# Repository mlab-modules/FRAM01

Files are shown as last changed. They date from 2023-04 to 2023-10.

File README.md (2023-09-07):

# MLAB module with FRAM memory - CY15B108QN

The MLAB module with FRAM ([Ferroelectric Random Access Memory](https://en.wikipedia.org/wiki/Ferroelectric_RAM)) [CY15B108QN](https://www.infineon.com/dgdl/Infineon-CY15B108QN_CY15V108QN_Excelon(TM)_LP_8-Mbit_(1024K_X_8)_Serial_(SPI)_F-RAM-DataSheet-v11_00-EN.pdf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) provides a unique combination of features that outperform traditional forms of non-volatile memories such as Flash or EEPROM.

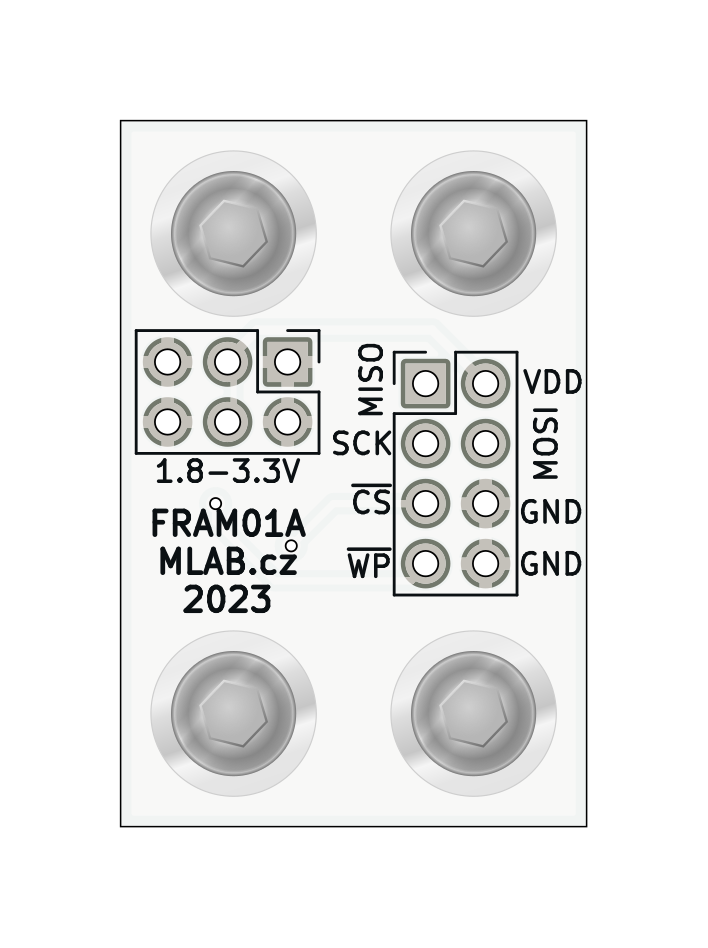
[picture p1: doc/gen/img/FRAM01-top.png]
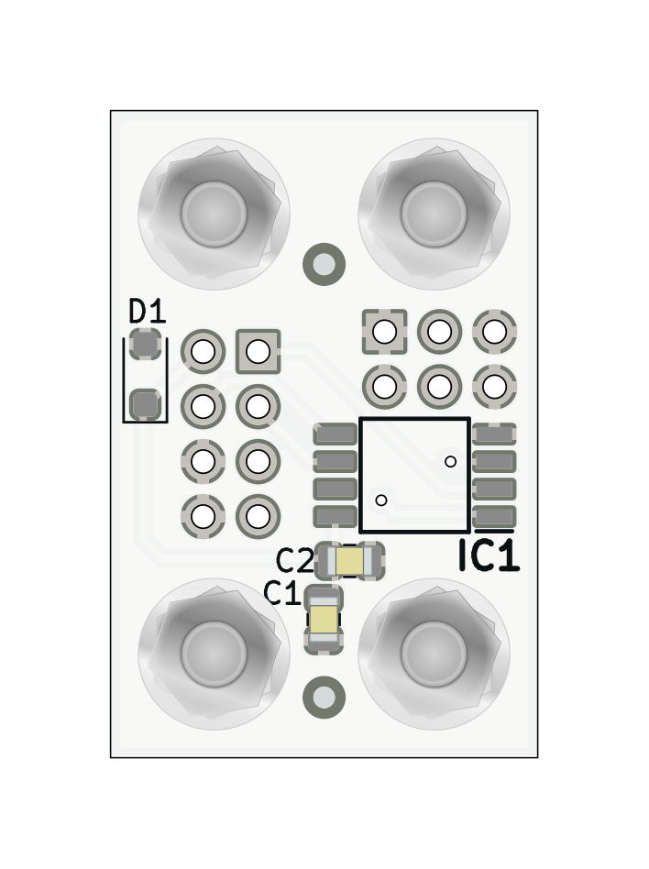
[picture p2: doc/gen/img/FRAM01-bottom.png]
  

## Advantages of FRAM memory

FRAM, also known as Ferroelectric Random Access Memory, offers a range of key advantages that differentiate it and make it suitable for various applications:

1. **Fast data write**: FRAM allows fast data write with speeds comparable to the read speed. This property is much faster than writing data to Flash or EEPROM memories. 

2. **Low power consumption**: The process of writing to FRAM requires less energy than writing to Flash or EEPROM memories due to high speed. 

3. **Very high write/read cycles**: FRAM can undergo approximately 10¹⁵ write and read cycles, which is much more than other forms of non-volatile memories.

4. **High radiation resistance**: Due to its unique physical operation principle, FRAM is more resistant to radiation than other types of memories. The ferroelectric material used to store data can hold an electrical charge without the need for power. This means that once a bit is written to a memory cell, it stays there until something physically changes it. This property, known as polarization, allows FRAM to resist ionizing radiation that can cause random changes in the value of the charge in other types of memories.

For a more comprehensive understanding of FRAM, you can refer to the [FRAM Wikipedia page](https://en.wikipedia.org/wiki/Ferroelectric_RAM).

## Suitable use cases for FRAM memory

Thanks to these unique properties, FRAM is suitable for a range of applications, including:

1. **Industrial automation**: For quick data logging and applications that require a large number of writes.

2. **Energy measurement**: Where there is a need to write data quickly and frequently with low energy consumption.

3. **Automotive applications**: FRAM is resistant to radiation and temperature fluctuations, making it ideal for use in the automotive industry.

4. **Aerospace and defense applications**: Thanks to its resistance to ionizing radiation, FRAM is an ideal choice for applications that are exposed to high levels of radiation.

## Parameters of CY15B108QN FRAM memory

- Capacity: 8 Mbit (1024K x 8)
- Power supply: 1.8V to 3.6V
- Interface: SPI, up to 40 MHz
- Write speed: 14 ns
- Endurance: 10^15 write and read cycles
- Data retention: 151 years at 85°C

For detailed information on CY15B108QN FRAM memory, please refer to the [datasheet](https://www.infineon.com/dgdl/Infineon-CY15B108QN_CY15V108QN_Excelon(TM)_LP_8-Mbit_(1024K_X_8)_Serial_(SPI)_F-RAM-DataSheet-v11_00-EN.pdf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).

This module is perfectly tailored for demanding applications that require high write speed, high reliability and durability, and low power consumption. Take advantage of the benefits of FRAM memory in the MLAB module with CY15B108QN.

## Module schematics
Link to FRAM01 schematic

## Overview of the MLAB module form factor

The [MLAB](https://mlab.cz/) modules provide a standard for developing modular solutions. They offer versatile usage as they can be either standalone modules for specific tasks or used as building blocks for more complex systems. The compact form factor along with the robust design of the MLAB modules ensures their effectiveness in a variety of applications. The MLAB system contains a wide range of electronic modules, each serving a specific function, which allows for great flexibility in designing electronic systems.

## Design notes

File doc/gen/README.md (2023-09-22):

# PCB

Board size: 19.81x29.97 mm (0.78x1.18 inches)

- This is the size of the rectangle that contains the board
- Thickness: 1.6 mm (63 mils)
- Material: FR4
- Finish: None
- Layers: 2
- Copper thickness: 35 µm

Solder mask: TOP / BOTTOM

- Color: Green

Silk screen: TOP / BOTTOM

- Color: White

Stackup:

| Name | Type | Color | Thickness | Material | Epsilon_r | Loss tangent |
|---|---|---|---|---|---|---|
| F.SilkS | Top Silk Screen | | | | | |
| F.Paste | Top Solder Paste | | | | | |
| F.Mask | Top Solder Mask | | 10 | | | |
| F.Cu | copper | | 35 | | | |
| dielectric 1 | core | | 1510 | FR4 | 4.5 | 0.020 |
| B.Cu | copper | | 35 | | | |
| B.Mask | Bottom Solder Mask | | 10 | | | |
| B.Paste | Bottom Solder Paste  | | | | | |
| B.SilkS | Bottom Silk Screen | | | | | |

# Important sizes

Clearance: 0.2 mm (8 mils)

Track width: 0.25 mm (10 mils)

- By design rules: 0.2 mm (8 mils)

Drill: 0.5 mm (20 mils)

- Vias: 0.5 mm (20 mils) [Design: 0.4 mm (16 mils)]
- Pads: 1.1 mm (43 mils)
- The above values are real drill sizes, they add 0.1 mm (4 mils) to plated holes (PTH)

Via: 0.8/0.4 mm (31/16 mils)

- By design rules: 0.4/0.3 mm (16/12 mils)
- Micro via: yes [0.2/0.1 mm (8/4 mils)]
- Buried/blind via: yes
- Total: 2 (thru: 2 buried/blind: 0 micro: 0)

Outer Annular Ring: 0.15 mm (6 mils)

- By design rules: 0.3 mm (12 mils)

Eurocircuits class: 4B
- Using min drill 0.5 mm for an OAR of 0.15 mm

# General stats

Components count: (SMD/THT)

- Top: 0/6 (THT)
- Bottom: 6/0 (SMD)

Defined tracks:

Used tracks:

- 0.25 mm (10 mils) (1) defined: no
- 0.3 mm (12 mils) (7) defined: no
- 0.3 mm (12 mils) (18) defined: no
- 0.4 mm (16 mils) (3) defined: no

Defined vias:

Used vias:

- 0.8/0.4 mm (31/16 mils) (Count: 2, Aspect: 2.0 A) defined: no

Holes (excluding vias):

- 1.0 mm (39 mils) (14)
- 3.0 mm (118 mils) (4)

Oval holes:

Drill tools (including vias and computing adjusts and rounding):

- 0.5 mm (20 mils) (2)
- 1.1 mm (43 mils) (14)
- 3.1 mm (122 mils) (4)

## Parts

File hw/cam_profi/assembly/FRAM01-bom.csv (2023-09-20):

Component | Description | Part | References | Value | Footprint | Quantity Per PCB | Datasheet | ust_id | height | manufacturer_name | manufacturer_part_number | mouser part number | mouser price/stock
1 |  | C_Small-Device-ISM02A-rescue | C2 | 100nF | C_0805_2012Metric | 1 |  | 5c70984712875079b91f8b4c
2 |  | C_Small-Device-ISM02A-rescue | C1 | 10uF | C_0805_2012Metric | 1 |  | 5c70984812875079b91f8bbe
3 |  | D_ZENER-MLAB_D | D1 | BZT52H-C3V6,115 | D_SOD-123F | 1 | BZT52H-C3V6,115 | 650b35ab462c6d9e720543d0
4 | F-RAM Excelon LP 40 MHz 8-EIAJ | CY15B108QN-40SXI | IC1 | CY15B108QN-40SXI | SOIC127P800X203-8N | 1 | https://www.mouser.in/datasheet/2/196/CYPR_S_A0011123055_1-3004611.pdf | 650b3dae462c6d9e72054477 | 2.03 | Infineon / Cypress | CY15B108QN-40SXI | 727-CY15B108QN-40SXI | https://www.mouser.co.uk/ProductDetail/Infineon-Cypress/CY15B108QN-40SXI?qs=P1JMDcb91o4DSS%2FkAQM5uA%3D%3D
5 | 2x03 2.54 mm pitch header, 2 pins next to each other are connected | HEADER_2x03_PARALLEL | J1 | HEADER_2x03_PARALLEL | PinHeader_2x03_P2.54mm_Vertical | 1
6 | 2x04 2.54 mm pitch header | HEADER_2x04 | J2 | HEADER_2x04 | PinHeader_2x04_P2.54mm_Vertical | 1

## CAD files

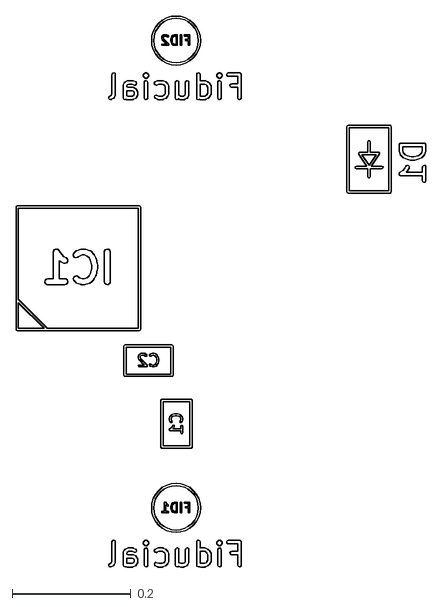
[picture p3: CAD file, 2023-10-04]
doc/gen/dxf/FRAM01-B_Fab.dxf
0.691 x 0.928

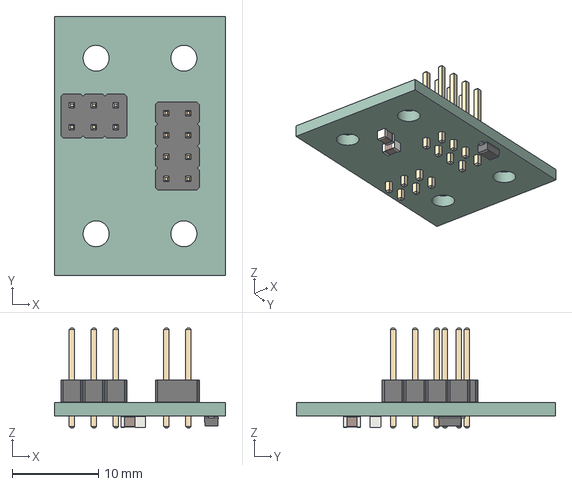
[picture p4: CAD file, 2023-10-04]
doc/gen/FRAM01.step
19.8 x 30.0 x 11.5 mm
tmpsu2gkpzn PCB

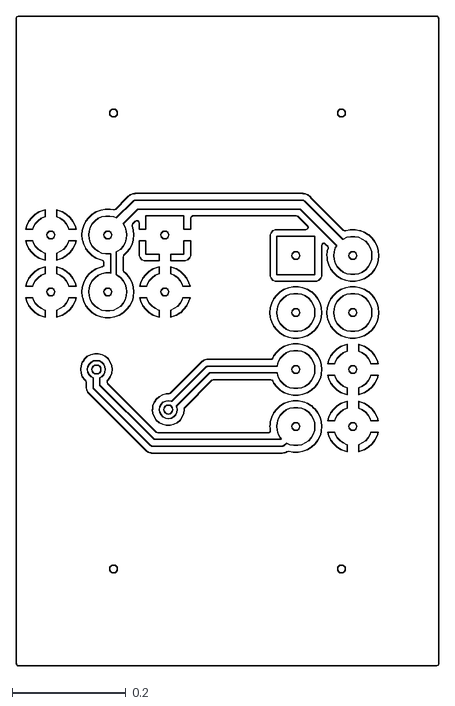
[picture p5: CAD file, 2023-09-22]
doc/gen/dxf/FRAM01-F_Cu.dxf
0.741 x 1.14

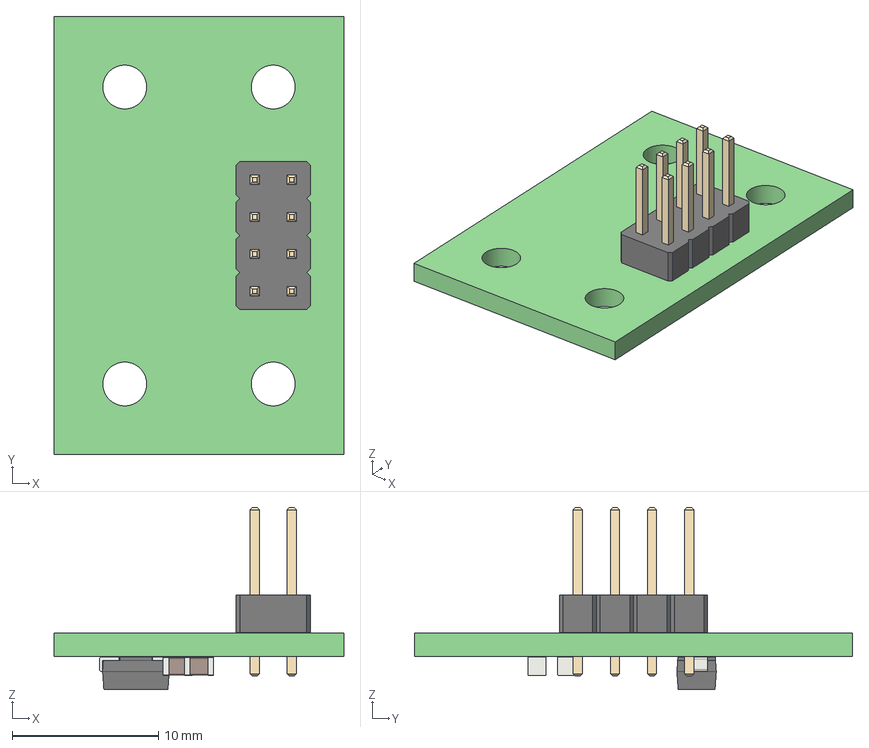
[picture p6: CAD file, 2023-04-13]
doc/gen/FRAM01A.step
19.8 x 30.0 x 12.5 mm
tmpce5b5qsc PCB

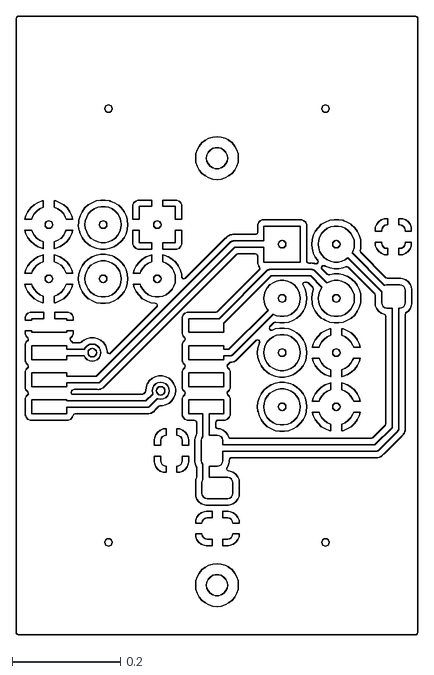
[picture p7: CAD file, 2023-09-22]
doc/gen/dxf/FRAM01-B_Cu.dxf
0.741 x 1.14

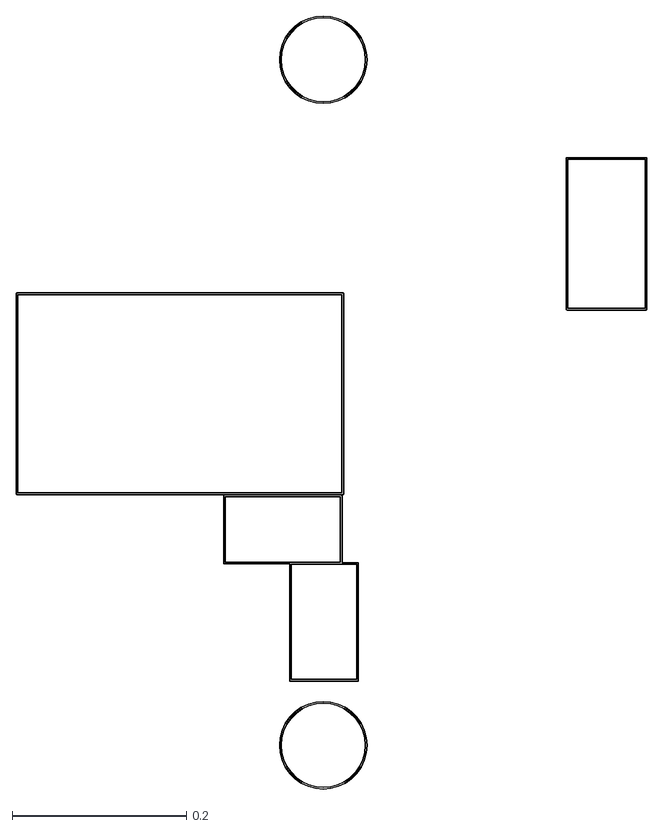
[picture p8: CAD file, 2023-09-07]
doc/gen/dxf/FRAM01-B_Courtyard.dxf
0.724 x 0.888

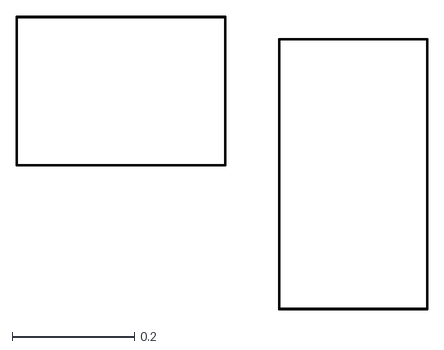
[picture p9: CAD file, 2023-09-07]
doc/gen/dxf/FRAM01-F_Courtyard.dxf
0.673 x 0.479

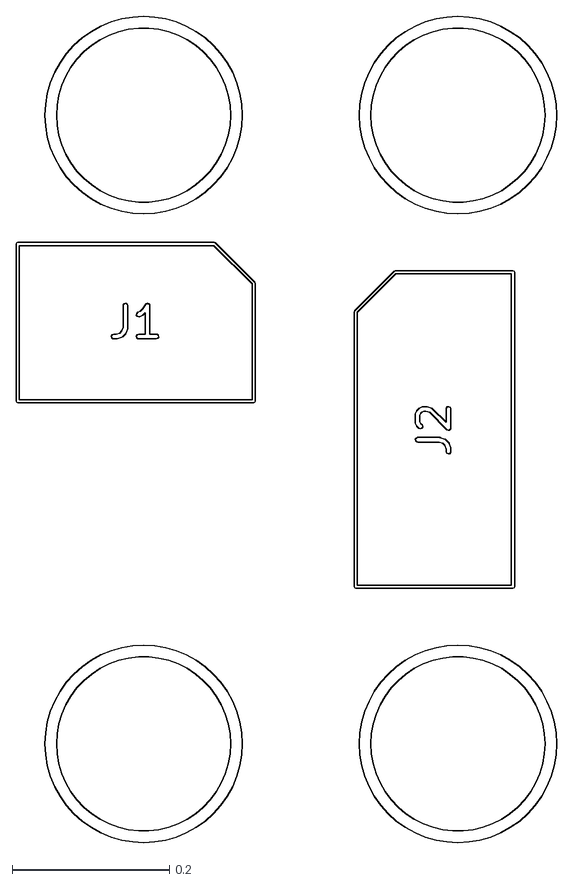
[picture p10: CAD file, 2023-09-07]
doc/gen/dxf/FRAM01-F_Fab.dxf
0.688 x 1.05

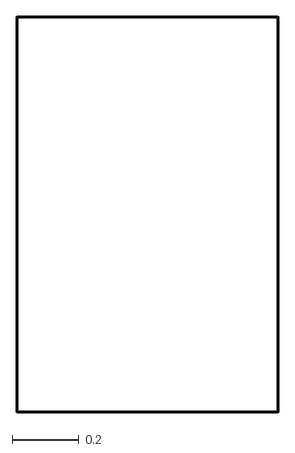
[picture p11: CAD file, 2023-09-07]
doc/gen/dxf/FRAM01-Edge_Cuts.dxf
0.785 x 1.19

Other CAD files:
doc/gen/dxf/FRAM01A-User_4.dxf
doc/gen/dxf/FRAM01A-User_2.dxf
doc/gen/dxf/FRAM01-Margin.dxf
doc/gen/dxf/FRAM01A-B_Adhesive.dxf
doc/gen/dxf/FRAM01A-User_Eco1.dxf
doc/gen/dxf/FRAM01A-User_Eco2.dxf
doc/gen/dxf/FRAM01-User_5.dxf
doc/gen/dxf/FRAM01-User_4.dxf
doc/gen/dxf/FRAM01A-User_3.dxf
doc/gen/dxf/FRAM01-B_Adhesive.dxf
doc/gen/dxf/FRAM01-B_Mask.dxf
doc/gen/dxf/FRAM01-B_Paste.dxf
doc/gen/dxf/FRAM01-B_Silkscreen.dxf
doc/gen/dxf/FRAM01-F_Adhesive.dxf
doc/gen/dxf/FRAM01-F_Mask.dxf
doc/gen/dxf/FRAM01-F_Paste.dxf
doc/gen/dxf/FRAM01-F_Silkscreen.dxf
doc/gen/dxf/FRAM01-User_1.dxf
doc/gen/dxf/FRAM01-User_2.dxf
doc/gen/dxf/FRAM01-User_3.dxf
doc/gen/dxf/FRAM01-User_6.dxf
doc/gen/dxf/FRAM01-User_7.dxf
doc/gen/dxf/FRAM01-User_8.dxf
doc/gen/dxf/FRAM01-User_9.dxf
doc/gen/dxf/FRAM01-User_Comments.dxf
doc/gen/dxf/FRAM01-User_Drawings.dxf
doc/gen/dxf/FRAM01-User_Eco1.dxf
doc/gen/dxf/FRAM01-User_Eco2.dxf
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

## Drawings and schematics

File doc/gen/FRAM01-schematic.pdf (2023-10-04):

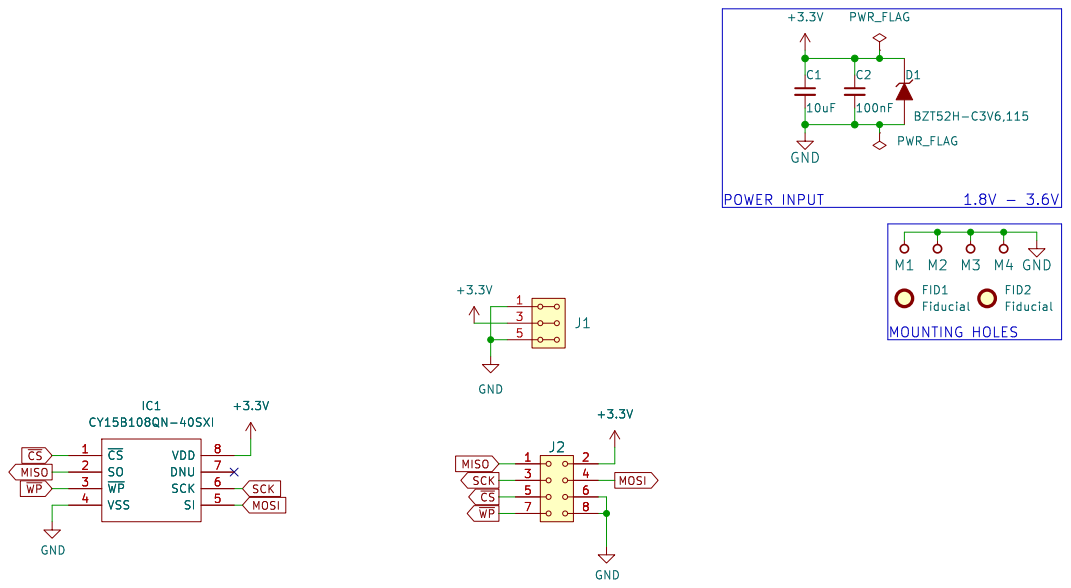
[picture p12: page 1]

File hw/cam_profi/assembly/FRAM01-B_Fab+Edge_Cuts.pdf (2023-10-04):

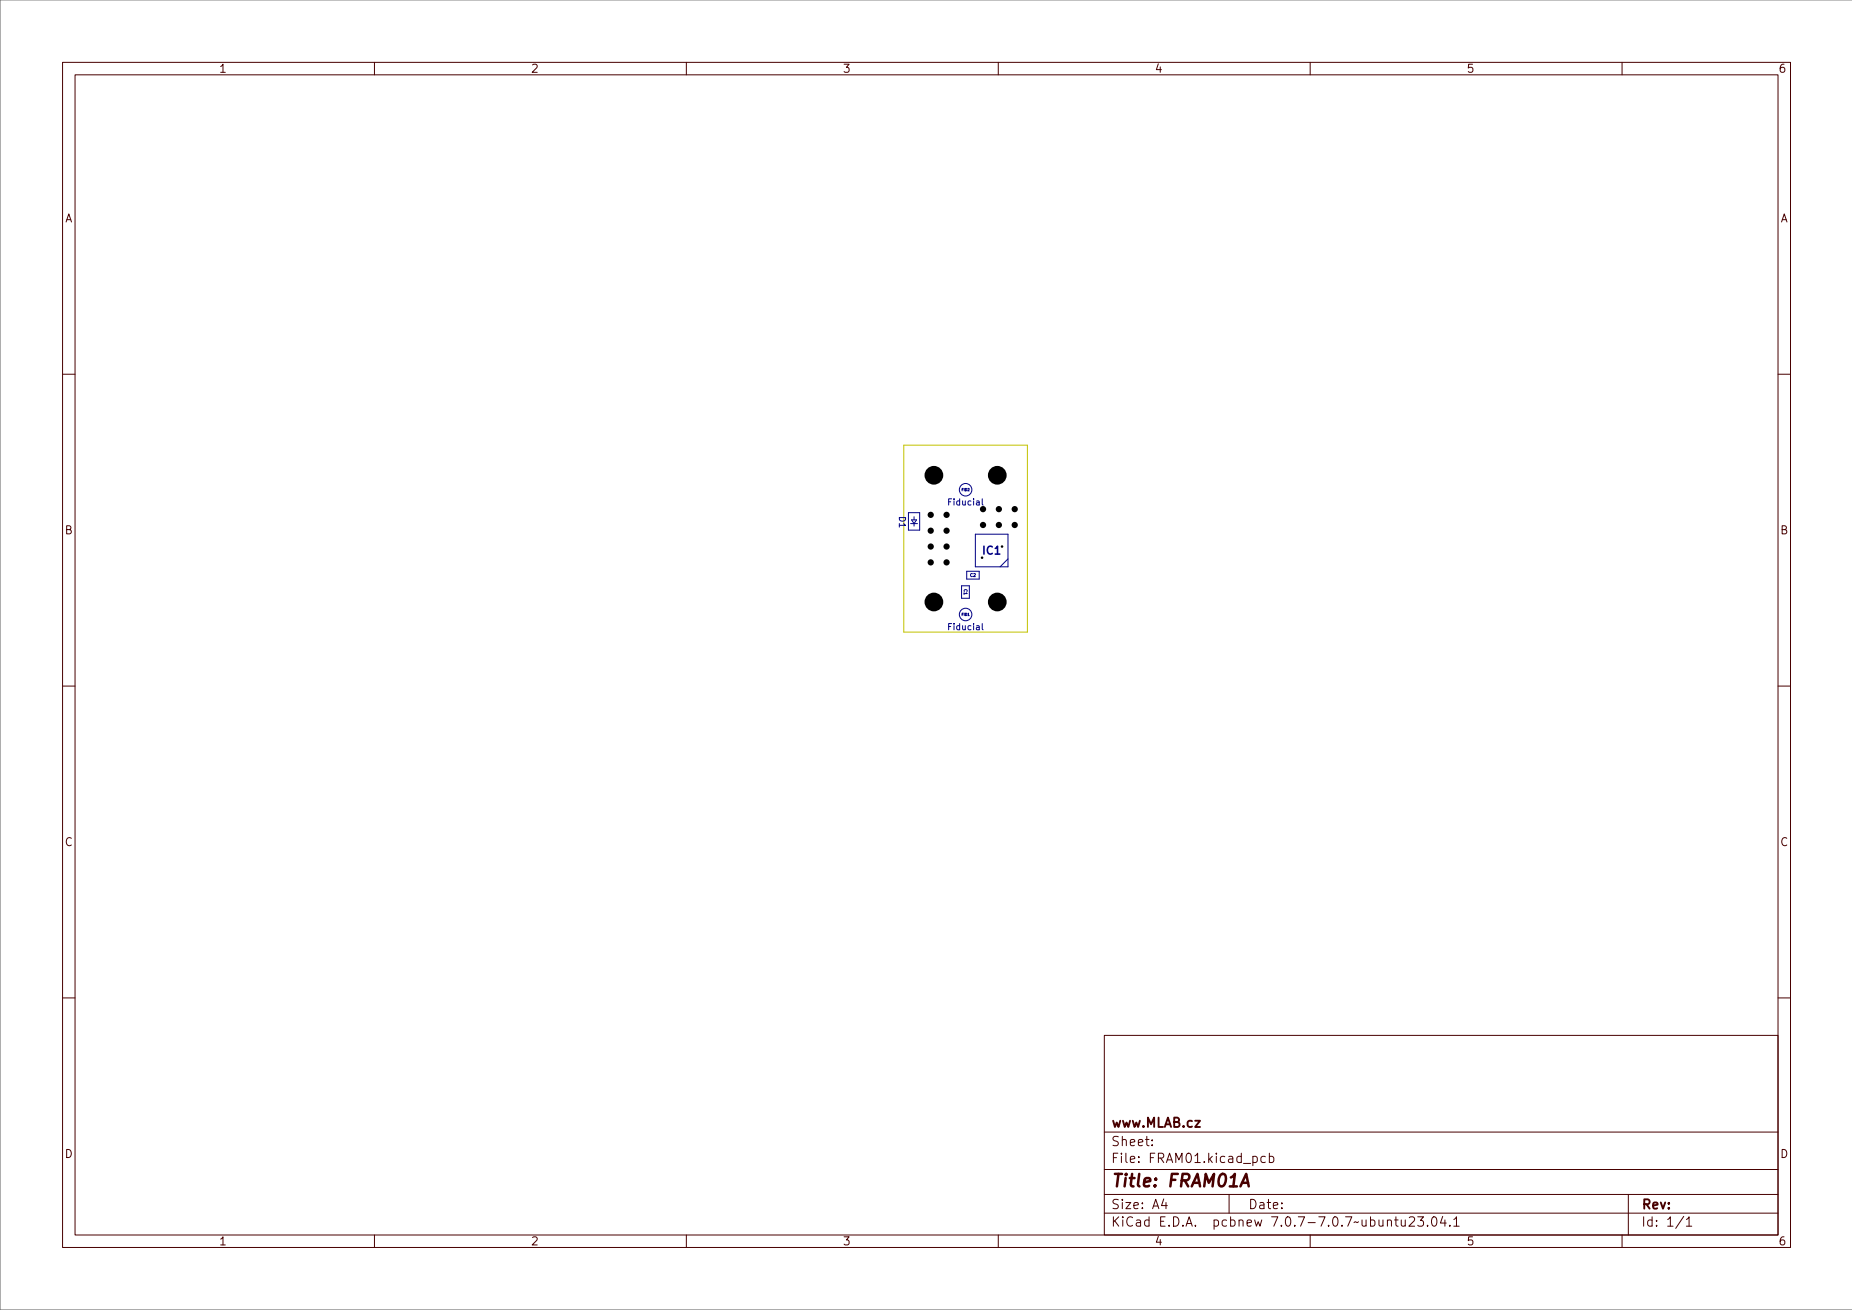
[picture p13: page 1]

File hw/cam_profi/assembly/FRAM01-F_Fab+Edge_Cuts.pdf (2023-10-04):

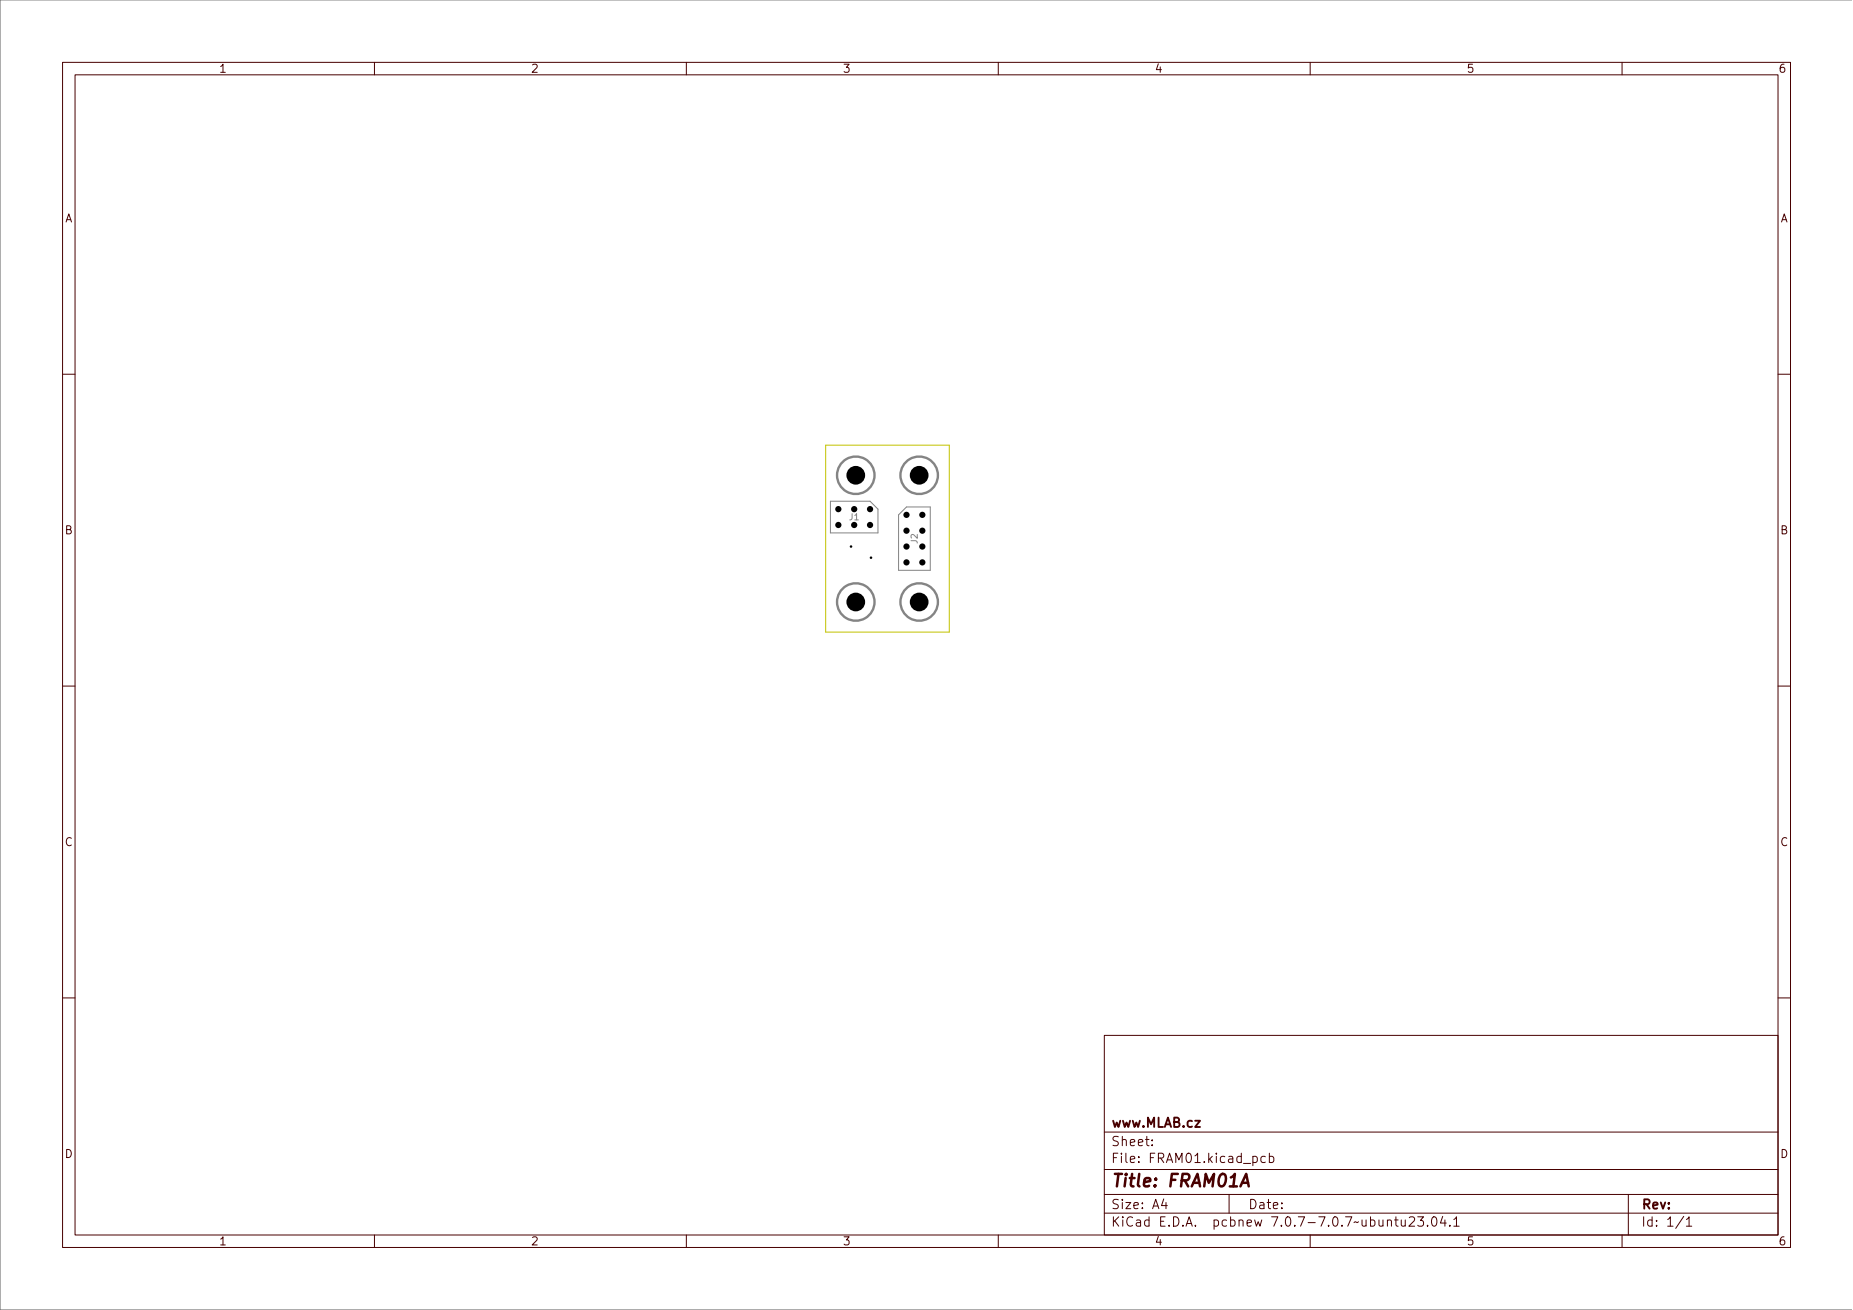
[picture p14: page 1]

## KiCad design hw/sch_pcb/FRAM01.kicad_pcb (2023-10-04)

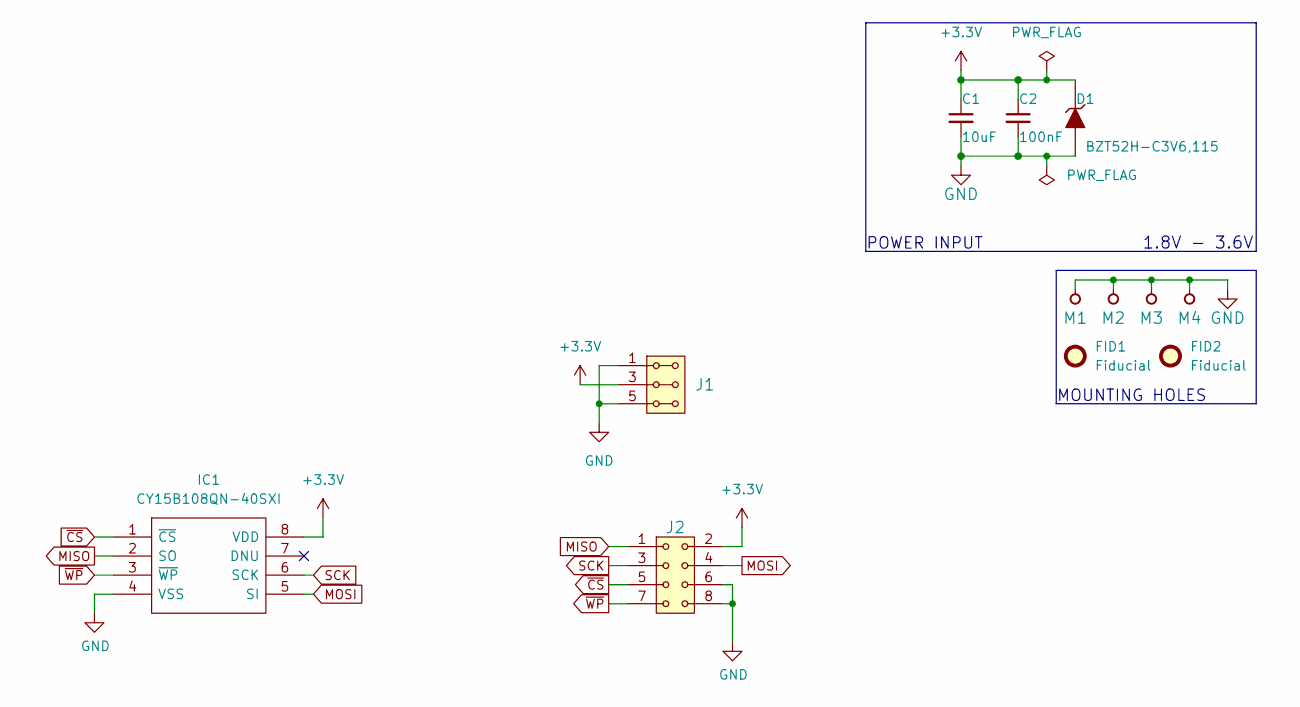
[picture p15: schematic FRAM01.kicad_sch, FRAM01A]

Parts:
C1: 10uF; C_0805_2012Metric
C2: 100nF; C_0805_2012Metric
D1: BZT52H-C3V6,115; D_SOD-123F
FID1, FID2: Fiducial; Fiducial_1mm_Mask2mm
IC1: CY15B108QN-40SXI; SOIC127P800X203-8N; Mouser Part Number 727-CY15B108QN-40SXI
J1: HEADER_2x03_PARALLEL; PinHeader_2x03_P2.54mm_Vertical
J2: HEADER_2x04; PinHeader_2x04_P2.54mm_Vertical
M1, M2: HOLE M3; MountingHole_3mm
M3, M4: HOLE; MountingHole_3mm

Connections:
+3.3V: C1.1, C2.1, D1.1 (K), IC1.8 (VDD), J1.3, J1.4, J2.2
GND: C1.2, C2.2, D1.2 (A), IC1.4 (VSS), J1.1, J1.2, J1.5, J1.6, J2.6, J2.8, M1.1, M2.1, M3.1, M4.1
MISO: IC1.2 (SO), J2.1
MOSI: IC1.5 (SI), J2.4
SCK: IC1.6 (SCK), J2.3
~CS: IC1.1 (~CS), J2.5
~WP: IC1.3 (~WP), J2.7

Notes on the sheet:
1.8V - 3.6V
POWER INPUT
MOUNTING HOLES

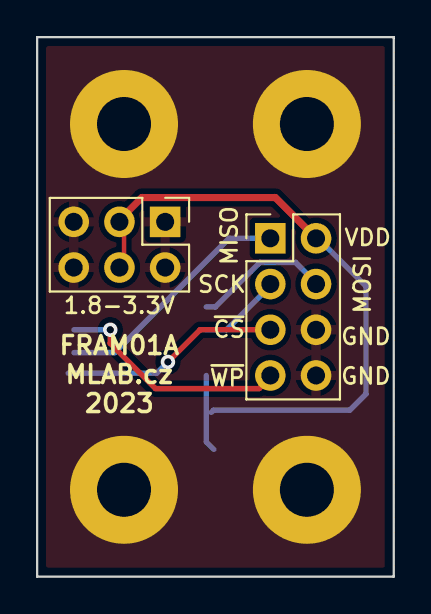
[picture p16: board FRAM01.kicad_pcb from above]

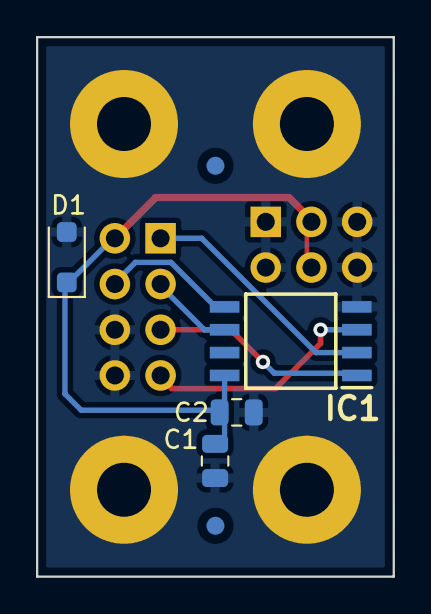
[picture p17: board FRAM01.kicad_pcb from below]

Board: 2 copper layers, 19.8 x 30.0 mm, 12 parts (6 on the bottom side), 7 nets.

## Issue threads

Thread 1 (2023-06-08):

SPI interface pinout

kaklik, 2023-06-08:
Vidím že konektor pro připojení má nyní takovýhle pinout:

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

Kam se to bude připojovat? Přijde mi, že to neodpovídá žádnému současnému rozložení konektorů.

Sommema4, 2023-08-25:
Jo, já jsem tohle rozložení našel jako rozložení pro SPI. Nevím přesně, kde jsem to našel. Už je to nějaká doba, kdy jsem to dělal. Stejný rozložení jsem použil například u ALTIMET02.
Je tam akorát přidaný ještě jeden "řádek", aby se dal využít Write Protection pin. Ten pin lze připojit na Vcc a nepoužívat ho. Tím se může ten konektor zredukovat o 2 piny. Snažil jsem se zachovat co nejvíc funkcionalit toho IC, proto je tam takový rozložení.

kaklik, 2023-09-07:
Ok, vypadá to, že je to docela [běžný rozložení](https://duckduckgo.com/?q=spi+avr+connector+pinout&t=ffab&iar=images&iax=images&ia=images) jen z toho popisu na PCB mi to nebylo jasný.

Closed 2023-09-07.

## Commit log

2023-01-12 Add files via upload
    KiCAD schematics
    [FRAM01A.kicad_pcb, FRAM01A.kicad_sch]
2023-01-16 pcb layout
    [FRAM01A.kicad_pcb, FRAM01A.kicad_sch]
2023-01-17 thicker traces
    [FRAM01A.kicad_pcb]
2023-01-19 Enable github actions. Change repository structure.
    [FRAM01A.kicad_pcb, FRAM01A.kicad_sch]
2023-01-19 Update actions products
    [FRAM01A-B_Adhesive.dxf, FRAM01A-B_Courtyard.dxf, FRAM01A-B_Cu.dxf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]
2023-04-13 pcb layout update, ready for check
    [FRAM01A.kicad_pcb, FRAM01A.kicad_sch]
2023-04-13 smaller pcb layout 1x2
    [FRAM01A-B_Courtyard.dxf, FRAM01A-B_Cu.dxf, FRAM01A-B_Fab.dxf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]
2023-06-08 Fix DRC and ERC errors. Update title block.
    [FRAM01A.kicad_pcb, FRAM01A.kicad_sch]
2023-07-05 automated commit; rename source files to new naming convence
    [FRAM01.kicad_pcb, FRAM01.kicad_sch]
2023-09-06 power connection added, SPI connector changed
    [FRAM01.kicad_pcb, FRAM01.kicad_sch]
2023-09-06 change zener diode, minor improvements in silkscreen
    [FRAM01.kicad_pcb, FRAM01.kicad_sch]
2023-09-06 add fiducial
    [FRAM01.kicad_pcb, FRAM01.kicad_sch]
2023-09-07 Split silkscreen to avoid collision with vias. Update title-block
    [FRAM01.kicad_pcb, FRAM01.kicad_sch]
2023-09-07 power connection added, SPI connector changed, cherrypick, simple repairs
    [FRAM01.kicad_pcb, FRAM01.kicad_sch]
2023-09-20 add ustid
    [FRAM01.kicad_sch]
2023-09-20 fram layout
    [FRAM01.kicad_pcb, FRAM01.kicad_sch]
2023-09-22 Kontrola a upravy PCB pred vyrobou
    [FRAM01.kicad_pcb]
2023-10-04 Edit B.Fab
    [FRAM01.kicad_pcb]
